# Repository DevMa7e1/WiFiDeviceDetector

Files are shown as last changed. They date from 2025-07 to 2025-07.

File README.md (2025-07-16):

# WiFiDeviceDetector
### **A simple Raspberry Pi based device detector that uses a Ralink RT5370-based WiPi dongle to detect if there are any wifi enabled devices nearby.**
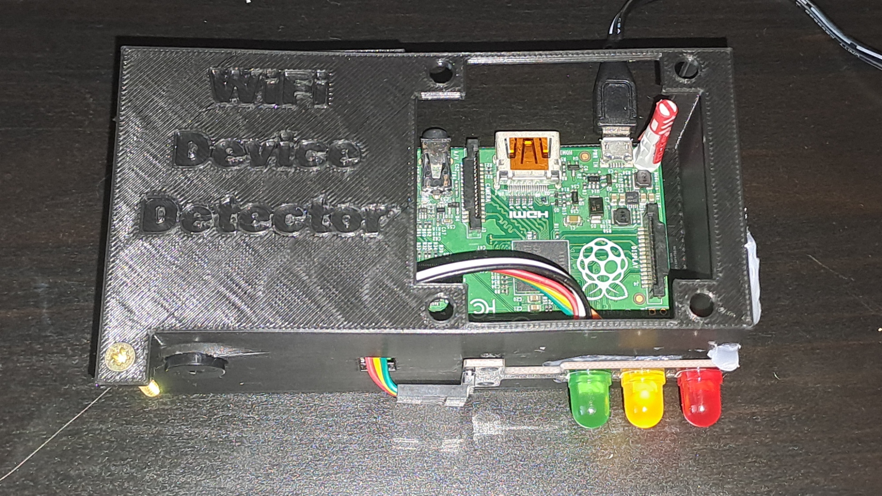
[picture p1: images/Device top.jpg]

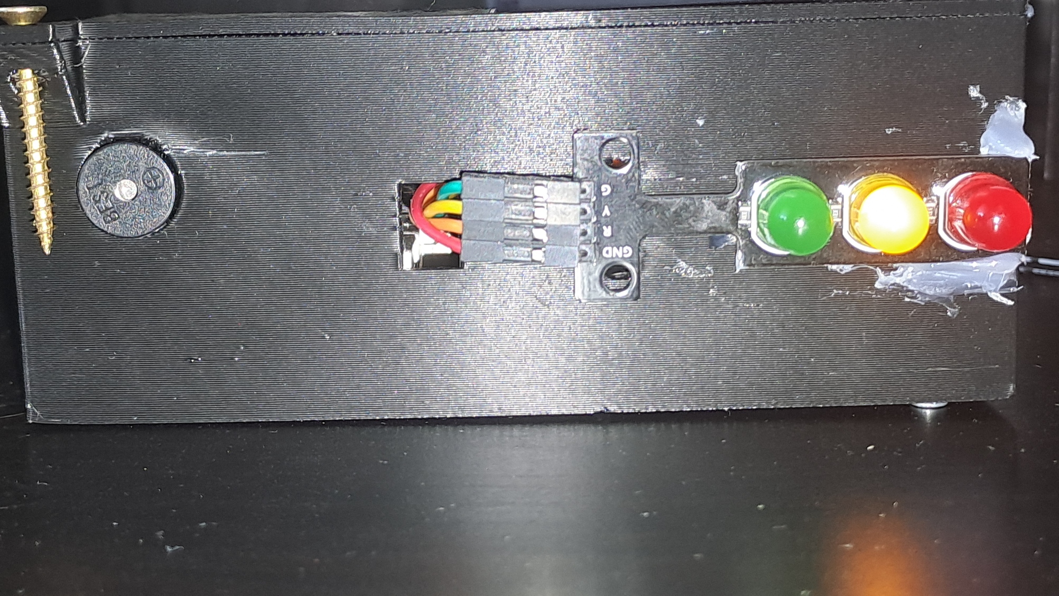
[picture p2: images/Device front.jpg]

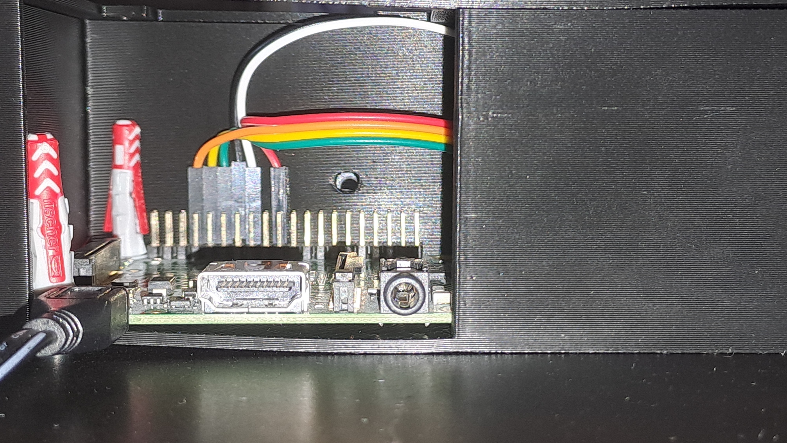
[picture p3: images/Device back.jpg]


# How does it work?

The WiPi dongle contains a Wi-Fi chip manufactured by Ralink. That chip has the ability to go into something called Monitor Mode. In this mode, the chip can pick up wifi signals and decode them. It turns out that, whenever a device wants to look for wifi networks, it has two options:

1. Wait for the router(s) to send a periodic signal containing their information (very slow).

2. Send a request for all routers to send their info on their respective channel.

Usually, a device chooses the second option. Now, in Monitor Mode, the Ralink chip can pick up those requests and, using their signal strength, determine how far the device is. The signal strength is then used to determine the severity:

* < -70 dBm - extremely far away (severity score 0)

* -70 to -50 dBm - far away to nearby (severity score 1)

* -50 to ∞ dBm - close to extremely close (severity score 2)

Each severity score has a color on the traffic light module:

* 0 - Green

* 1 - Yellow

* 2 - Red

The severity also decays over time. The time in which severity decays can be set by adjusting the severity_timeout variable in main.py.

### Notes:

In my build, I have resorted to hot-gluing because the dimensions weren't quite right for the traffic light module (in the 3D files it's fine). There is supposed to be a 60mm fan on the top, but mine wouldn't power on with the 5V from the RPi rev 1.2.

# How to replicate it?

It is quite simple to replicate what I've done. First, let's start with the physical part of the project:

1. Get yourself a Raspberry Pi 1, 2, or 3 (it might work with a 4 or 5, but I have not tested it) </sup> model B+, a WiFi adapter with a chip that has the ability to be put into Monitor Mode, an active buzzer, an LED traffic light module <sup> or three LEDs </sup>, a 60mm 5v fan <sup> a 12v one might work </sup> and a handful of wires (female-to-male and female-to-female).

2. Connect the traffic light module using some female-to-female wires to the pins:

* GND - GND

* RED - GP14

* YELLOW - GP15

* GREEN - GP18

3. Connect the buzzer:

* GND - GND

* VCC - GP32

4. Plug in the WiFi dongle and the power cable.

    **If you have 3D printed the case:**

5. Disconnect the wires from the LED traffic light module's pins for a moment.

6. Route the wires through the rectangular hole.

7. Reconnect the wires to the module's pins.

8. Screw in the traffic light module.

9. Push part of the buzzer through the hole next to the traffic light module.

10. Screw in the fan.

11. Using your favorite method, connect the fan:

* VCC - DC 5V

* GND - GND

<sup>*I used Wago connectors with some male-to-male cables.</sup>

11. Screw in a screw in the screw hole on the top.

    **Physical part done!**

12. Connect to the RPi using ssh or keyboard + monitor.

13. Download the main.py file.

14. Install scapy (you can use `sudo apt install python3-scapy`).

    **All done!**

To run the script, just type in `sudo python3 main.py` (preferably over keyboard).

### Optional stuff:

You can create a rc.local file in /etc so that the script runs at startup! The syntax is just like a sh file. All you need to do is `sudo chmod 755 /etc/rc.local`.

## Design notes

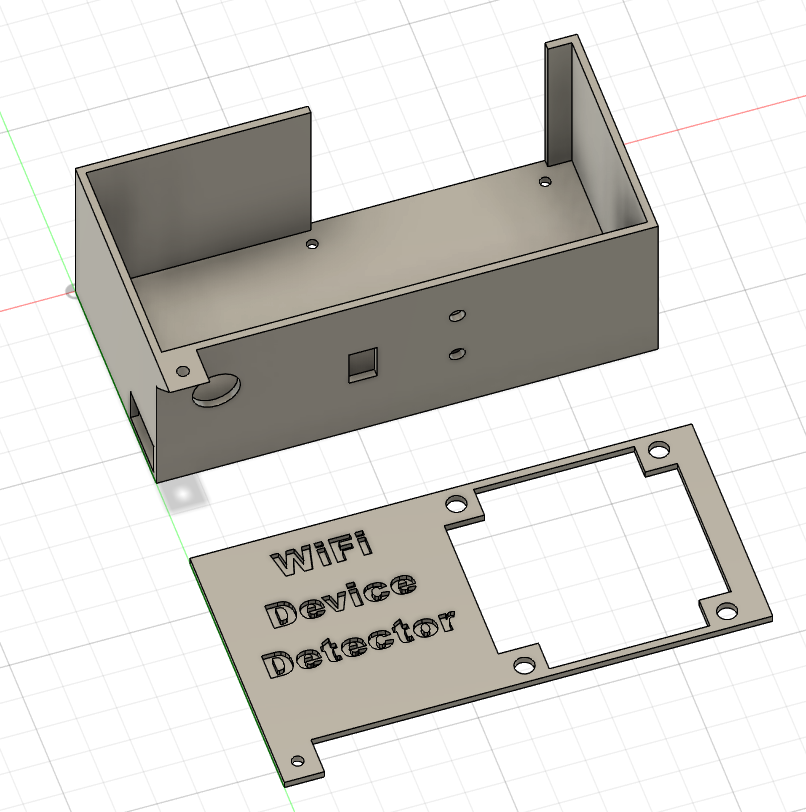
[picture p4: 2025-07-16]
images/Case Screenshot.png

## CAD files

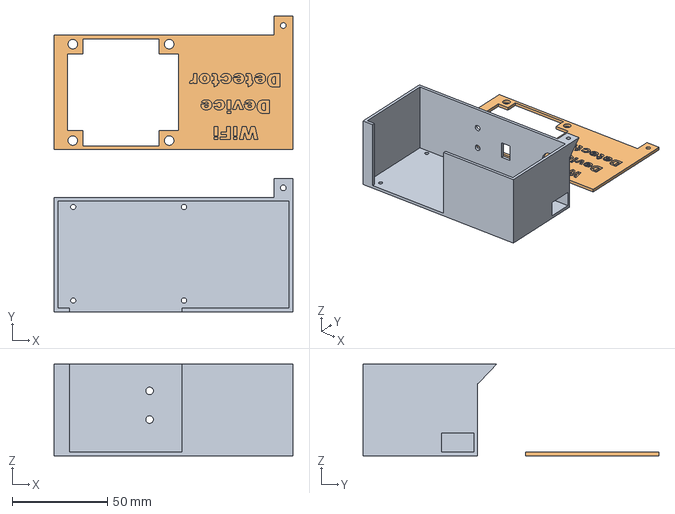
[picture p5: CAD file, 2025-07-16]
WiFi Device Detector Case.3mf
125.0 x 155.0 x 48.0 mm

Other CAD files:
WiFi Device Detector Case.f3d

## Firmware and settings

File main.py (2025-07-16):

from scapy.all import sniff, Dot11, Dot11ProbeReq, RadioTap
from gpiozero import LED, Buzzer
from os import system
import time, datetime, threading

# Run python script as sudo!

green = LED(18)
yellow = LED(15)
red = LED(14)
buzzer = Buzzer(23)

green.off()
yellow.off()
red.off()
buzzer.off()

interface = "wlan0"
det_treshold = -70
mac_timeout = 10

devices = {}

severity_index = 0
severity_time = 0
severity_timeout = 10

channels = [1, 2, 3, 4, 5, 6, 7, 8, 9, 10, 11, 12, 13]
channel_index = 0

def rssi_to_dis(rssi):
    if rssi <= -60:
        return "very far away"
    elif rssi <= -50:
        return "far away"
    elif rssi <= -40:
        return 'nearby'
    elif rssi <= -30:
        return 'closely'
    elif rssi <= 0:
        return 'extremely closely'
def rssi_to_severity(rssi):
    if rssi >= -70 and rssi <= -50:
        return 1
    elif rssi >= -50:
        return 2

def display_severity():
    global severity_index
    match severity_index:
        case 2:
            green.off()
            yellow.off()
            red.on()
        case 1:
            green.off()
            yellow.on() #Keep red on if already in case of decay
        case 0:
            red.off()
            yellow.off()
            green.on()

def handle_severity(stop_event):
    global severity_time, severity_timeout, severity_index
    try:
        while not stop_event.is_set():
            if severity_time+severity_timeout < time.time():
                if severity_index > 0 :
                    severity_index -= 1
                    severity_time = time.time()
            display_severity()
            time.sleep(0.1)
    except KeyboardInterrupt:
                print("Quitting handle.")
                quit()
def hop_channels(stop_event):
    global channels, channel_index
    time.sleep(2)
    while not stop_event.is_set():
        time.sleep(1)
        status = system(f"sudo iw dev {interface} set channel {str(channels[channel_index])}")
        if status != 0:
            print("Hopping error...")
        channel_index = (channel_index+1) % len(channels)
    print("Hop quitting!")

def pk_handle(packet):
    global devices, severity_index, severity_time
    if packet.haslayer(Dot11ProbeReq):
        mac_address = packet.addr2
        rssi = -999

        if packet.haslayer(RadioTap):
            if hasattr(packet[RadioTap], 'dBm_AntSignal'):
                rssi = packet[RadioTap].dBm_AntSignal
            elif hasattr(packet[RadioTap], 'dBm_antsignal'):
                rssi = packet[RadioTap].dbm_antsignal
        if rssi >= det_treshold:
            c_time = time.time()
            if mac_address not in devices or (c_time - devices[mac_address] > mac_timeout):
                print(f"[{datetime.datetime.now().strftime('%H:%M:%S')}] Device {mac_address} detected {rssi_to_dis(rssi)} @ RSSI {rssi} dBm.")
                match rssi_to_severity(rssi):
                    case 1:
                        if severity_index < 2:
                            severity_index = 1
                            severity_time = c_time
                            buzzer.beep(on_time=0.5, off_time=0.5, n=2, background=True)
                    case 2:
                        severity_index = 2
                        severity_time = c_time
                        buzzer.beep(on_time=1, off_time=1, n=5, background=True)
                devices[mac_address] = c_time
if __name__ == "__main__":
    print(f"Setting {interface} to monitor mode...")
    system(f"""systemctl stop NetworkManager
ip link set {interface} down
iw dev {interface} set type monitor
ip link set {interface} up""")
    print("Done!")
    print(f"Starting detector on {interface}...")
    stop_event = threading.Event()
    threading.Thread(target=handle_severity, args=(stop_event,)).start()
    threading.Thread(target=hop_channels, args=(stop_event,)).start()
    try:
        sniff(iface=interface, prn=pk_handle, store=False)
    except KeyboardInterrupt:
        print("Quitting.")
        stop_event.set()
        green.off()
        yellow.off()
        red.off()
        buzzer.off()
        system(f"""sudo ip link set {interface} down
sudo iw dev {interface} set type managed
sudo ip link set {interface} up
sudo systemctl restart NetworkManager""")
    except Exception as e:
        print(f'Failed because of {e}')
    finally:
        stop_event.set()
        system(f"""sudo ip link set {interface} down
sudo iw dev {interface} set type managed
sudo ip link set {interface} up
sudo systemctl restart NetworkManager""")

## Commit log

2025-07-16 Some code improvements + case
    The code now works well and I have also made a nice little case for the device. I have also included some images of the final result.
    [WiFi Device Detector Case.3mf, WiFi Device Detector Case.f3d]
2025-07-16 Better readme
    documentation, les go!
2025-07-16 Demo video
    what should I write here 🤔
